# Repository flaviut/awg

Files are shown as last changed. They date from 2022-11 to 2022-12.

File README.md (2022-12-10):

# Arbitrary Waveform Generator

**DOES NOT WORK**, see issues

## Goals

- 0-15MHz
- drive a 50-ohm load
- ±3.3V output voltage

## Credits

Rebuilt from the ground up, but originally derived from the following:

- https://www.instructables.com/Arbitrary-Wave-Generator-With-the-Raspberry-Pi-Pic/
- https://www.instructables.com/Poor-Mans-Waveform-Generator-Based-on-RP2040-Raspb/
- https://github.com/F6ITU/AWG

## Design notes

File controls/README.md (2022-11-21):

The optional controls board for this device

Broken out into a separate board in order to reduce JLCPCB cost, as well as
because it can probably be done by hand-soldering to panel-mounted components.

Designed to be placed on the left side of the LCD display, and clipped into a
3d-printed enclosure.

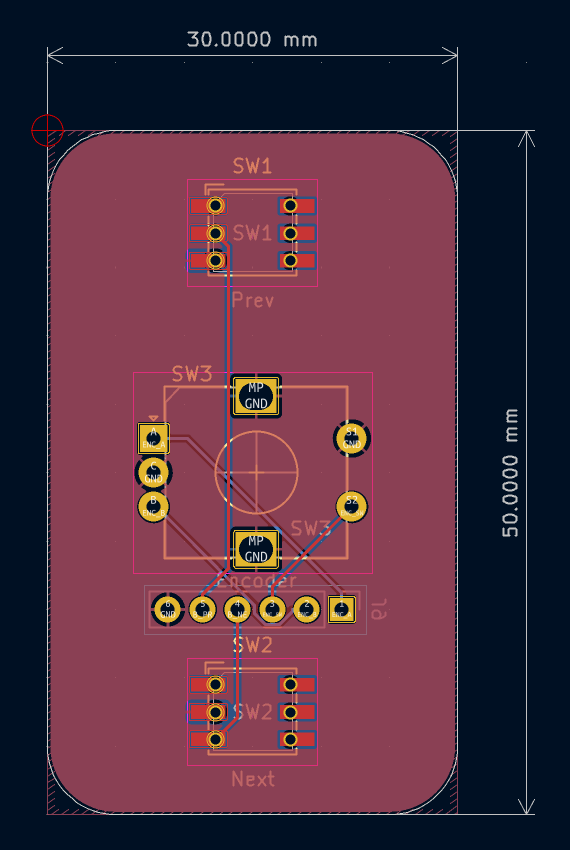
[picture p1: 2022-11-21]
controls/board layout.png

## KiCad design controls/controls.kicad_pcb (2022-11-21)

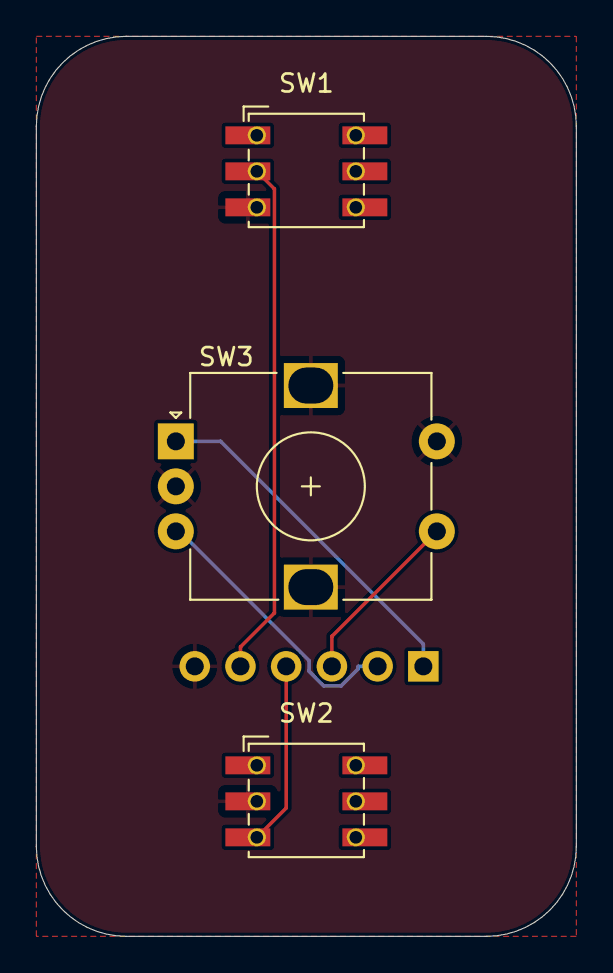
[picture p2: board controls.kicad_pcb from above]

Board: 2 copper layers, 30.0 x 50.0 mm, 4 parts (1 on the bottom side), 6 nets.

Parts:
J9: Controls; PinSocket_1x06_P2.54mm_Vertical
SW1: Prev; Square_PB
SW2: Next; Square_PB
SW3: Encoder; RotaryEncoder_Alps_EC12E-Switch_Vertical_H20mm

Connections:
/B_NE: J9.4, SW2.3 (C)
/B_PR: J9.5, SW1.2 (B)
/ENC_A: J9.1, SW3.A
/ENC_B: J9.2, SW3.B
/ENC_SW: J9.3, SW3.S2
GND: J9.6, SW1.3 (C), SW2.2 (B), SW3.C, SW3.MP, SW3.S1

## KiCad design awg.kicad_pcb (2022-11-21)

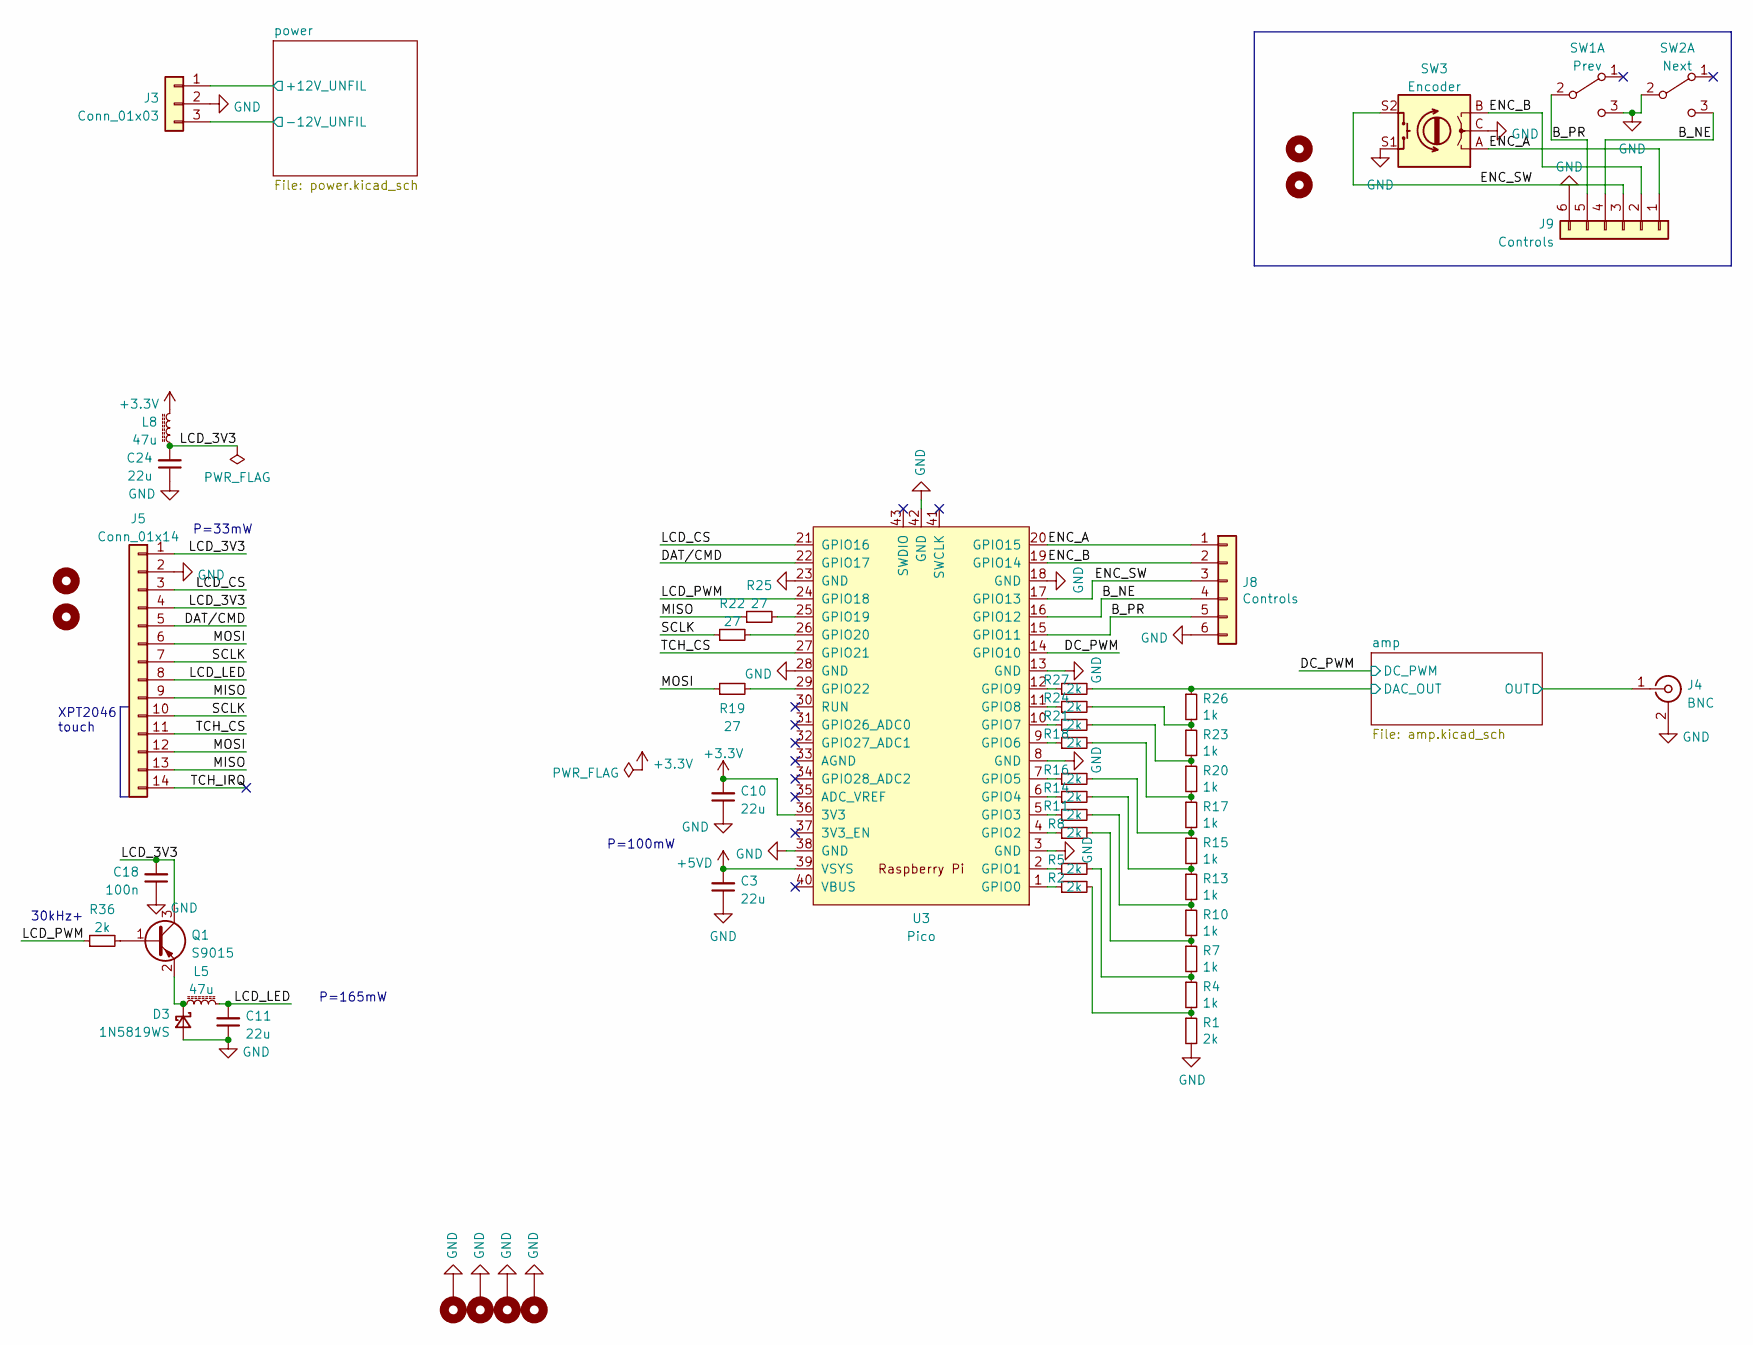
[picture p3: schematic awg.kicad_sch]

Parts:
C3, C10, C11, C24: 22u; C_1210_3225Metric; LCSC C12891
C18: 100n; C_0603_1608Metric; LCSC C57112
D3: 1N5819WS; D_SOD-323; LCSC C191023
H1, H2, H5, H6: MountingHole; MountingHole_3.2mm_M3
J1, J2, J6, J7: Conn_01x01; MountingHole_3.2mm_M3_Pad_Via
J3: Conn_01x03; JST_XH_S3B-XH-A_1x03_P2.50mm_Horizontal; LCSC C132460
J4: BNC; BNC_DOSIN_801_0050_Horizontal; LCSC C521210
J5: Conn_01x14; PinSocket_1x14_P2.54mm_Vertical; LCSC C2897377
J8: Controls; PinHeader_1x06_P2.54mm_Vertical; LCSC C718239
J9: Controls; PinSocket_1x06_P2.54mm_Vertical; LCSC C706878
L5, L8: 47u; L_Taiyo-Yuden_NR-50xx; LCSC C341038
Q1: S9015; SOT-23; LCSC C2149
R1, R2, R5, R8, R11, R14, R16, R18, R21, R24, R27, R36: 2k; R_0603_1608Metric; LCSC C319701
R4, R7, R10, R13, R15, R17, R20, R23, R26: 1k; R_0603_1608Metric; LCSC C309080
R19, R22, R25: 27; R_0603_1608Metric; LCSC C22967
SW1: Prev; Square_PB; LCSC C318853
SW2: Next; Square_PB; LCSC C318853
SW3: Encoder; RotaryEncoder_Alps_EC12E-Switch_Vertical_H20mm
U3: Pico; RPi_Pico_SMD

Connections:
+3V3: C10.2, L8.1, U3.36 (3V3)
+5VD: C3.2, U3.39 (VSYS); also elsewhere on the board
/B_NE: J8.4, J9.4, SW2.3 (C), U3.16 (GPIO12)
/B_PR: J8.5, J9.5, SW1.2 (B), U3.15 (GPIO11)
/DAT/CMD: J5.5, U3.22 (GPIO17)
/DC_PWM: U3.14 (GPIO10); also elsewhere on the board
/ENC_A: J8.1, J9.1, SW3.A, U3.20 (GPIO15)
/ENC_B: J8.2, J9.2, SW3.B, U3.19 (GPIO14)
/ENC_SW: J8.3, J9.3, SW3.S2, U3.17 (GPIO13)
/LCD_3V3: C18.2, C24.2, J5.1, J5.4, L8.2, Q1.3 (C)
/LCD_CS: J5.3, U3.21 (GPIO16)
/LCD_LED: C11.2, J5.8, L5.2
/LCD_PWM: R36.1, U3.24 (GPIO18)
/MISO: J5.9, J5.13, R25.1
/MOSI: J5.6, J5.12, R19.1
/SCLK: J5.7, J5.10, R22.1
/TCH_CS: J5.11, U3.27 (GPIO21)
/TCH_IRQ: J5.14
/amp/DAC_OUT: R26.1, R27.2; also elsewhere on the board
/amp/OUT: J4.1 (In); also elsewhere on the board
/power/+12V_UNFIL: J3.1; also elsewhere on the board
/power/-12V_UNFIL: J3.3; also elsewhere on the board
GND: C3.1, C10.1, C11.1, C18.1, C24.1, D3.2 (A), J1.1, J2.1, J3.2, J4.2 (Ext), J5.2, J6.1, J7.1, J8.6, J9.6, R1.2, SW1.3 (C), SW2.2 (B), SW3.C, SW3.S1, U3.3 (GND), U3.8 (GND), U3.13 (GND), U3.18 (GND), U3.23 (GND), U3.28 (GND), U3.38 (GND), U3.42 (GND); also elsewhere on the board
unnamed: D3.1 (K), L5.1, Q1.2 (E)
unnamed: Q1.1 (B), R36.2
unnamed: R1.1, R2.2, R4.2
unnamed: R2.1, U3.1 (GPIO0)
unnamed: R4.1, R5.2, R7.2
unnamed: R5.1, U3.2 (GPIO1)
unnamed: R8.1, U3.4 (GPIO2)
unnamed: R7.1, R8.2, R10.2
unnamed: R10.1, R11.2, R13.2
unnamed: R11.1, U3.5 (GPIO3)
unnamed: R13.1, R14.2, R15.2
unnamed: R14.1, U3.6 (GPIO4)
unnamed: R15.1, R16.2, R17.2
unnamed: R16.1, U3.7 (GPIO5)
unnamed: R19.2, U3.29 (GPIO22)
unnamed: R22.2, U3.26 (GPIO20)
unnamed: R25.2, U3.25 (GPIO19)
unnamed: R17.1, R18.2, R20.2
unnamed: R18.1, U3.9 (GPIO6)
unnamed: R20.1, R21.2, R23.2
unnamed: R21.1, U3.10 (GPIO7)
unnamed: R23.1, R24.2, R26.2
unnamed: R24.1, U3.11 (GPIO8)
unnamed: R27.1, U3.12 (GPIO9)

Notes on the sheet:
30kHz+
P=33mW
P=165mW
P=100mW
XPT2046 touch

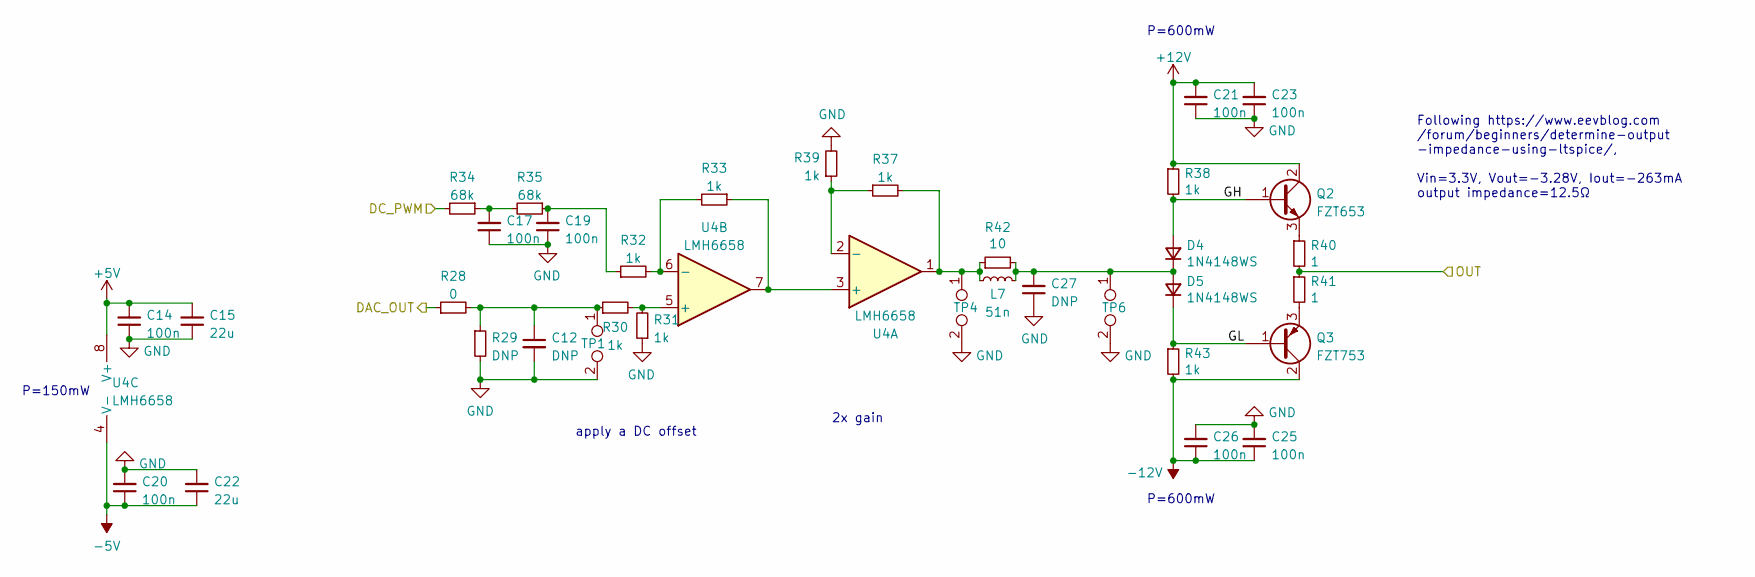
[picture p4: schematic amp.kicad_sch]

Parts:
C12, C27: DNP; C_0603_1608Metric
C14, C17, C19, C20, C21, C23, C25, C26: 100n; C_0603_1608Metric; LCSC C57112
C15, C22: 22u; C_1210_3225Metric; LCSC C12891
D4, D5: 1N4148WS; D_SOD-323; LCSC C2128
L7: 51n; L_Axial_L7.0mm_D3.3mm_P10.16mm_Horizontal_Fastron_MICC
Q2: FZT653; SOT-223-3_TabPin2; LCSC C780850
Q3: FZT753; SOT-223-3_TabPin2; LCSC C85794
R28: 0; R_0603_1608Metric; LCSC C21189
R29: DNP; R_0603_1608Metric
R30, R31, R32, R33, R37, R38, R39, R43: 1k; R_0603_1608Metric; LCSC C309080
R34, R35: 68k; R_0603_1608Metric; LCSC C23231
R40, R41: 1; R_1206_3216Metric; LCSC C17928
R42: 10; R_0603_1608Metric; LCSC C22859
TP1, TP4, TP6: TestPoint_2Pole; TestPoint_2Pads_Pitch2.54mm_Drill1mm
U4: LMH6658; SOIC-8_3.9x4.9mm_P1.27mm

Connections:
+5V: C14.2, C15.2, U4.8 (V+); also elsewhere on the board
+12V: C21.2, C23.2, Q2.2 (C), R38.1; also elsewhere on the board
-5V: C20.1, C22.1, U4.4 (V-); also elsewhere on the board
-12V: C25.1, C26.1, Q3.2 (C), R43.2; also elsewhere on the board
/DC_PWM: R34.2; also elsewhere on the board
/amp/DAC_OUT: R28.1; also elsewhere on the board
/amp/GH: D4.2 (A), Q2.1 (B), R38.2
/amp/GL: D5.1 (K), Q3.1 (B), R43.1
/amp/OUT: R40.2, R41.1; also elsewhere on the board
GND: C12.2, C14.1, C15.1, C17.1, C19.1, C20.2, C21.1, C22.2, C23.1, C25.2, C26.2, C27.1, R29.2, R31.1, R39.2, TP1.2, TP4.2, TP6.2; also elsewhere on the board
unnamed: C27.2, D4.1 (K), D5.2 (A), L7.2, R42.2, TP6.1
unnamed: C12.1, R28.2, R29.1, R30.1, TP1.1
unnamed: C17.2, R34.1, R35.2
unnamed: C19.2, R32.1, R35.1
unnamed: L7.1, R37.2, R42.1, TP4.1, U4.1
unnamed: Q2.3 (E), R40.1
unnamed: Q3.3 (E), R41.2
unnamed: R37.1, R39.1, U4.2 (-)
unnamed: R30.2, R31.2, U4.5 (+)
unnamed: R33.1, U4.3 (+), U4.7
unnamed: R32.2, R33.2, U4.6 (-)

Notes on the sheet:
Following https://www.eevblog.com /forum/beginners/determine-output -impedance-using-ltspice/, Vin=3.3V, Vout=-3.28V, Iout=-263mA output impedance=12.5Ω
2x gain
P=150mW
P=600mW
apply a DC offset

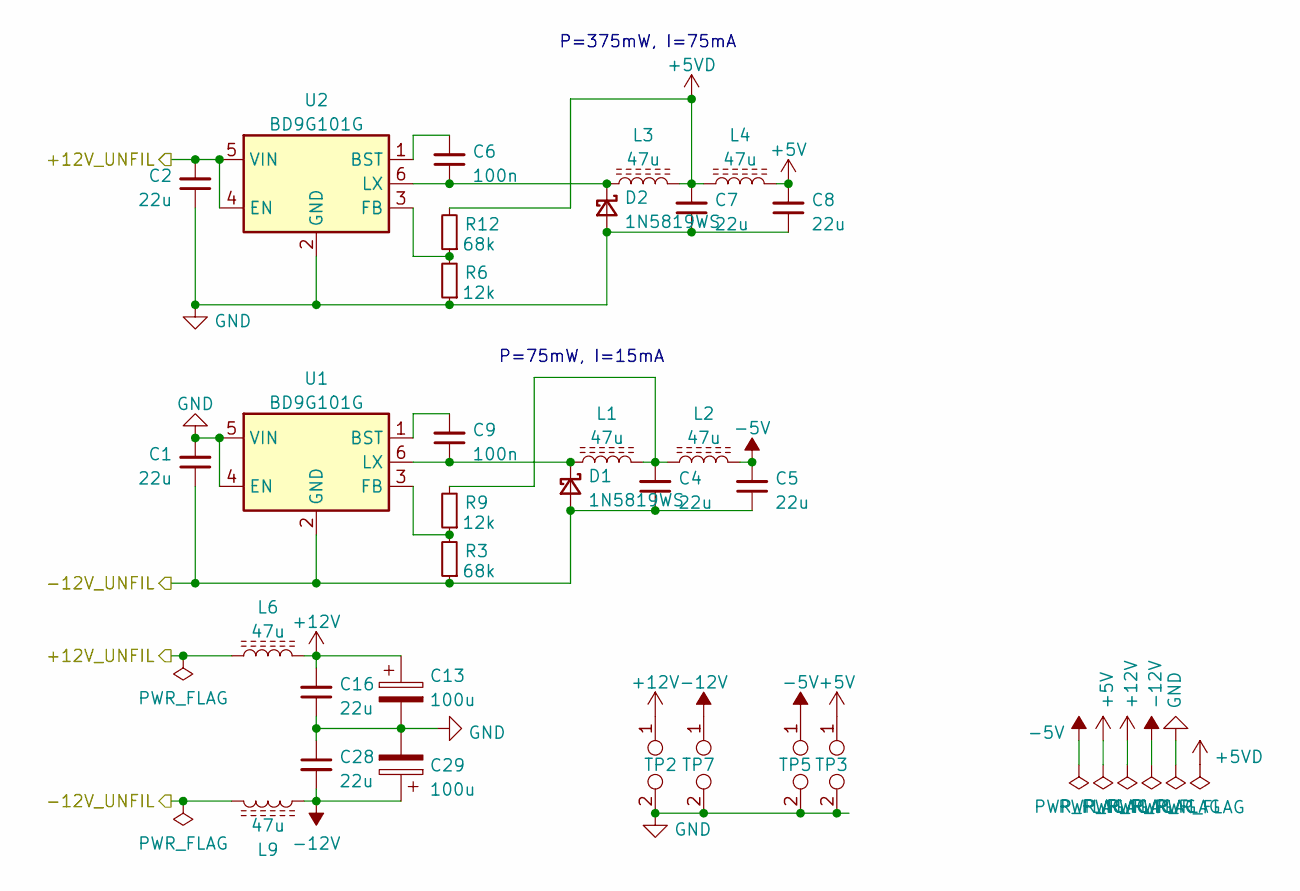
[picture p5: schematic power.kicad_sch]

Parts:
C1, C2, C4, C5, C7, C8, C16, C28: 22u; C_1210_3225Metric; LCSC C12891
C6, C9: 100n; C_0603_1608Metric; LCSC C57112
C13, C29: 100u; CP_Elec_6.3x5.4_Nichicon; LCSC C111600
D1, D2: 1N5819WS; D_SOD-323; LCSC C191023
L1, L2, L3, L4, L6, L9: 47u; L_Taiyo-Yuden_NR-50xx; LCSC C341038
R3, R12: 68k; R_0603_1608Metric; LCSC C23231
R6, R9: 12k; R_0603_1608Metric; LCSC C22790
TP2, TP3, TP5, TP7: TestPoint_2Pole; TestPoint_2Pads_Pitch2.54mm_Drill1mm
U1, U2: BD9G101G; SOT-23-6; LCSC C108761

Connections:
+5V: C8.2, L4.2, TP3.1; also elsewhere on the board
+5VD: C7.2, L3.2, L4.1, R12.2; also elsewhere on the board
+12V: C13.1, C16.2, L6.2, TP2.1; also elsewhere on the board
-5V: C5.2, L2.2, TP5.1; also elsewhere on the board
-12V: C28.2, C29.1, L9.2, TP7.1; also elsewhere on the board
/power/+12V_UNFIL: C2.2, L6.1, U2.4 (EN), U2.5 (VIN); also elsewhere on the board
/power/-12V_UNFIL: C1.1, C4.1, C5.1, D1.2 (A), L9.1, R3.1, U1.2 (GND); also elsewhere on the board
GND: C1.2, C2.1, C7.1, C8.1, C13.2, C16.1, C28.1, C29.2, D2.2 (A), R6.1, TP2.2, TP3.2, TP5.2, TP7.2, U1.4 (EN), U1.5 (VIN), U2.2 (GND); also elsewhere on the board
unnamed: C9.1, D1.1 (K), L1.1, U1.6 (LX)
unnamed: C9.2, U1.1 (BST)
unnamed: C6.1, D2.1 (K), L3.1, U2.6 (LX)
unnamed: C6.2, U2.1 (BST)
unnamed: C4.2, L1.2, L2.1, R9.2
unnamed: R3.2, R9.1, U1.3 (FB)
unnamed: R6.2, R12.1, U2.3 (FB)

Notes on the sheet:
P=75mW, I=15mA
P=375mW, I=75mA

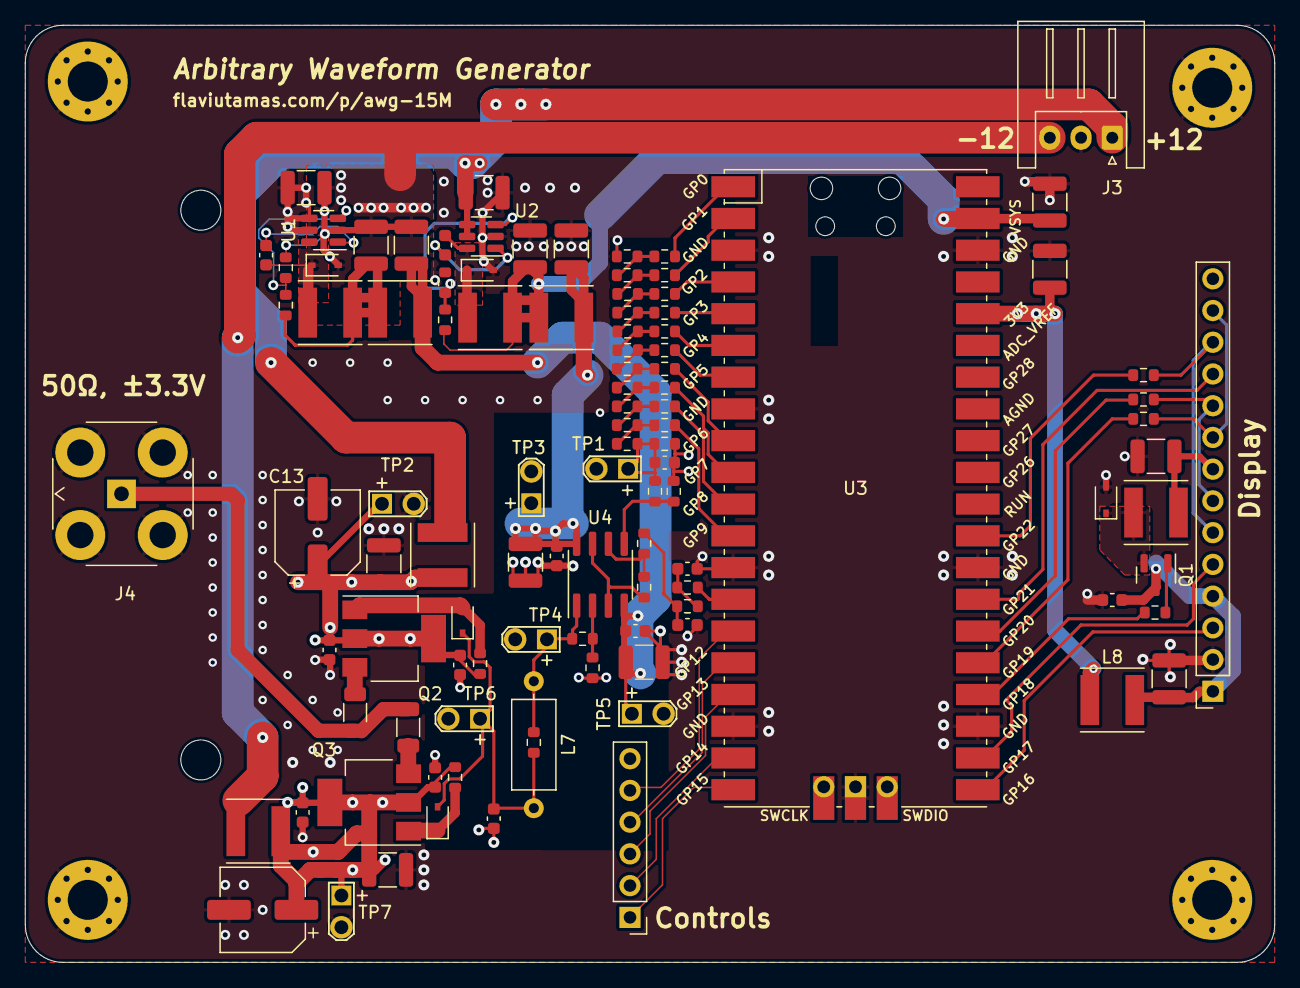
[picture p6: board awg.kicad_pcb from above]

Board: 4 copper layers, 100.0 x 75.0 mm, 110 parts (0 on the bottom side), 70 nets.

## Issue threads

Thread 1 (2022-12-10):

-5V power supply broken

flaviut, 2022-12-10:
The -5V power supply fails to generate -5V.

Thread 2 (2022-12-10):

Output transistors get hot

flaviut, 2022-12-10:
Perhaps reducing the voltage provided to them will improve this? At the moment, it is 12V, but testing shows that the final output stage only has a dropout of perhaps a volt, so switching their power rail to ±5V would also work (and reduce complexity elsewhere)

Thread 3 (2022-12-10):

C29 is reversed

flaviut, 2022-12-10:
Explodes when power is applied.

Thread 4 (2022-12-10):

Redesign power topology

flaviut, 2022-12-10:
Ideally, +5V (USB connector, barrel jack) input, and -5V, +3.3V generated on board.

- need ~275mA from +5V
- need ~200mA from -5V

flaviut, 2023-01-03:
Current voltage regulator setup is completely incorrect for -5V.

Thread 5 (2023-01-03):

Use with 2.8" TFT 240xRGBx320 V1.1

flaviut, 2023-01-03:
The V1.1 of the display has different dimensions from the [original version in this drawing](http://www.lcdwiki.com/2.8inch_SPI_Module_ILI9341_SKU:MSP2807).

The versioning here is very unclear. I think this will work:

- 50mm tall
- holes 2.88mm from top & bottom
- holes 3.4mm tall, 10.5mm wide
- holes 79.6mm from left edge of screen PCB

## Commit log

2022-11-14 Rename power supply schematic
    [alim.kicad_pcb, powersupply.kicad_sch]
2022-11-20 Add kibot
    [AWG.kicad_pcb, AWG.kicad_sch, awg.kicad_pcb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]
2022-11-20 Make design more compact
    Fitting it on a 100x70mm PCB means it's far cheaper to produce
    [amp.kicad_sch, awg.kicad_pcb, awg.kicad_sch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]
2022-11-21 consistant fonts
    [awg.kicad_pcb]
2022-11-21 Add optional controls board
    [controls.kicad_pcb, controls.kicad_sch]
